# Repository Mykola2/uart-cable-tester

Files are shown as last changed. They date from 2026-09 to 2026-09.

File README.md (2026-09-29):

# RPi ↔ CUAV X7 telemetry cable tester

A production tester for the harness that runs from a Raspberry Pi 40-pin header to 3× JST-GH 6-pin (CUAV X7 TELEM1–3). Plug a cable in and get a PASS/FAIL verdict in under a second, with a colour per wire:

| Colour | Meaning |
|---|---|
| green | OK |
| red | open |
| orange | miswired (swapped, wrong cavity, wrong pin) |
| magenta | short |

A wiggle test catches intermittent crimps.

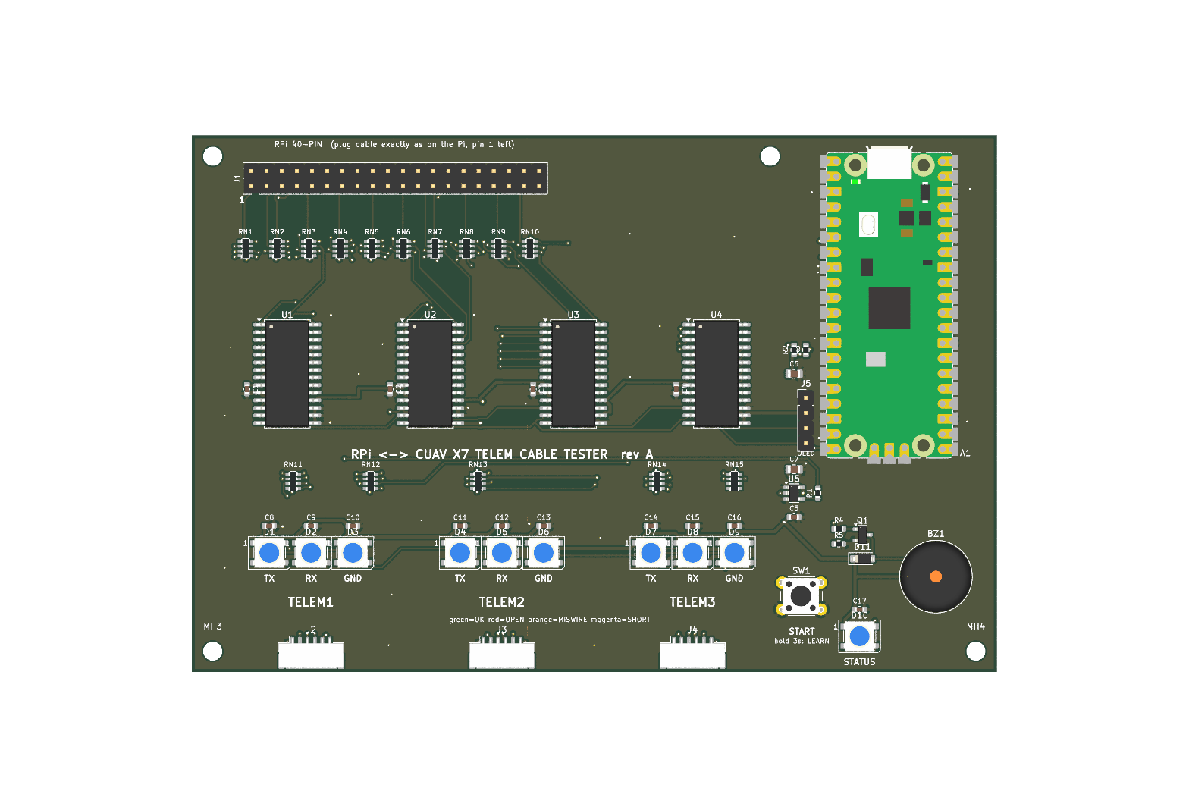
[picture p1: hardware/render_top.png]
board


## How it works
- **Test lines.** Every contact on the 40-pin header and on the three JSTs (58 lines) has its own MCP23017 I/O pin, through a 220 Ω resistor. The header's power and GND pins are isolated test lines too.
- **Scan.** The RP2040 drives one line low at a time and reads all the others (a "walking one" scan). That builds the full connection map, which it compares to `wiring.json`.
- **Changing the pinout** needs no new hardware. Either edit `wiring.json` on the board's USB drive, or plug in a known-good cable and hold the button for 3 s (learn mode).
- **Ground wires** may land on any Pi GND pin, because the Pi's grounds are common.

## Layout
| Path | Contents |
|---|---|
| `firmware/` | CircuitPython firmware and PC simulation tests. See [firmware/README.md](firmware/README.md). |
| `hardware/` | KiCad 9 project, generator and check scripts, BOM. See [hardware/README.md](hardware/README.md). |
| `hardware/fab/` | JLCPCB order files: Gerber zip, `BOM_JLC.csv`, `CPL_JLC.csv`. |

## Quick commands
```bash
python firmware/pc_tests/test_tester.py      # firmware logic tests
python hardware/check_design.py              # netlist vs firmware pin map
python hardware/make_jlc.py                  # regenerate JLCPCB files from the board
```

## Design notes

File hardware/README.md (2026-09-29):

# Cable tester PCB (KiCad 9)

`design.py` is the single source of truth: parts, footprints, pin-to-net map and positions.
Everything else is generated from it.

| File | What it is |
|---|---|
| `cable_tester.kicad_sch` | Schematic. Every pin is connected by a net label; opens normally in KiCad. |
| `cable_tester.kicad_pcb` | Board, 135×90 mm, 2 layers. Routed with Freerouting, GND pours on both layers. DRC is clean apart from silkscreen warnings. |
| `BOM.csv` | Grouped BOM with MPNs. `fab/BOM_JLC.csv` has the verified LCSC numbers. |
| `fab/` | JLCPCB files (Gerber zip, BOM, CPL), regenerated by `make_jlc.py`. |
| `move_decoupling.py` | One-off fix already applied to the routed board: moved C1–C4 next to the MCP23017 VDD pins. |
| `cable_tester_schematic.pdf`, `render_top.png`, `render_bottom.png` | Previews of the schematic and the board. |

## Regenerate

```bash
python gen_schematic.py
"C:/Program Files/KiCad/9.0/bin/kicad-cli.exe" sch erc cable_tester.kicad_sch
"C:/Program Files/KiCad/9.0/bin/kicad-cli.exe" sch export netlist --format kicadsexpr -o cable_tester.net cable_tester.kicad_sch
python check_design.py
"C:/Program Files/KiCad/9.0/bin/python.exe" gen_pcb.py
```

`check_design.py` checks the exported netlist against `firmware/hwmap.py`:
- each of the 58 test lines runs connector pin → 220 Ω → the MCP23017 pin the firmware expects
- the address straps are correct
- no DUT pin touches a power net

**The board is routed, so don't run `gen_pcb.py` again**, because it overwrites the board.
After that, make changes in the schematic (or `design.py` followed by `gen_schematic.py`), then use *Tools → Update PCB from Schematic* (F8).

## Circuit summary
- **A1**: Raspberry Pi Pico or a WeAct RP2040 (USB-C, same pinout).
  - USB supplies VBUS (+5 V), which powers the LEDs and buzzer.
  - The module's 3V3 output powers the MCP23017s.
  - Pins used: GP4 SDA, GP5 SCL, GP14 buzzer, GP15 button, GP16 LED data.
- **U1–U4**: MCP23017 at I²C addresses 0x20–0x23. Every DUT contact goes to its own expander pin through one resistor in RN1–RN15 (4×220 Ω arrays).
  - U1: H1–16. U2: H17–32. U3: GPA = H33–40, GPB0–5 = TELEM1.
  - U4: GPA0–5 = TELEM2, GPB0–5 = TELEM3.
  - Spare lines: U3 GPB6–7, U4 GPA6–7, U4 GPB6–7.
- **J1**: the 40-pin header. **None of its pins touch GND, 3V3 or 5V.** Each one is an isolated test line, which is why any future pinout can be tested with a config change only.
- **D1–D10**: WS2812B, driven through U5 (74AHCT1G125) to shift the data line from 3.3 V to 5 V.
  - D1–D9 are the wire LEDs: TX / RX / GND for each TELEM connector.
  - D10 is the PASS/FAIL status LED.
- **BZ1**: 5 V active buzzer, switched by Q1 with flyback diode D11.
- **SW1**: START / LEARN button.
- **J5**: optional SSD1306 OLED header. The firmware doesn't drive it yet.

## Before ordering
1. **Route it.** Freerouting works well:
   - export with *File → Export → Specctra DSN*, route in Freerouting, then import the `.ses` file
   - press **B** to fill the GND pours
   - run DRC
2. **Check JST orientation in the 3D viewer (Alt+3).** The TELEM connectors must open toward the bottom board edge.
3. **Check the header orientation.** It copies a Pi seen from above: pin 1 is bottom-left on the silkscreen, and the even-pin row is along the board edge. The cable must plug in exactly as it does on the Pi.
4. **Check the module footprint.** If you use a Pico clone, confirm it matches `RaspberryPi_Pico_SMD_HandSolder`.
5. **JST-GH receptacles are consumables.** They are rated for only ~50 mating cycles. Order spares and replace them with hot air when mating gets loose.

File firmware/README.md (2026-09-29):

# Cable tester firmware (CircuitPython)

## Install
1. Hold BOOTSEL, plug in USB, and drop the CircuitPython UF2 for **Raspberry Pi Pico** onto the RPI-RP2 drive (circuitpython.org). The Pico build also runs on the WeAct RP2040.
2. Copy `code.py`, `hwmap.py`, `mcp_bus.py`, `tester.py` and `wiring.json` to the `CIRCUITPY` drive. No libraries are needed.
3. Open the serial console (Mu, Thonny or PuTTY at any baud rate). You should see `# cable tester ready` followed by a CSV header.

## Use
- **Plug the cable in.**
  - A good cable passes about 0.3 s after it's fully connected: all wire LEDs turn green, the status LED turns green, and it gives one short beep.
  - A fault that stays for 3 s gives FAIL: status LED red and a long beep. The wire LEDs show the fault type:

| Wire LED | Meaning |
|---|---|
| green | OK |
| red | OPEN |
| orange | MISWIRE (swapped, wrong cavity or wrong header pin) |
| magenta | SHORT |

- **Wiggle test.** After a PASS, flex the cable near each crimp. A fault that appears and clears within 2 s is logged as INTERMITTENT: the status LED blinks red and the affected wire LED blinks.
- **Unplug.** The tester returns to idle (status LED dim blue) after 1 s with nothing connected.
- **Short press:** during a test, forces the verdict now; after a verdict, starts a retest.
- **Hold 3 s with a known-good cable plugged in:** LEARN.
  - The tester stores the cable's wiring in NVM, prints it as JSON (ready to paste into `wiring.json`), and beeps once per net (9 beeps expected).
- **Hold 3 s with nothing plugged in:** clears the learned map and goes back to `wiring.json`.
- Editing `wiring.json` also overrides an old learned map.

The serial log is CSV (`time_s,count,result,faults`), e.g. `412.3,57,FAIL,T2_RX OPEN [T2.3] | [H7]`.

## Pinout changes
Edit `wiring.json` on the CIRCUITPY drive, or use LEARN.
- Pins are named `H1`–`H40` (RPi header numbering) and `T1.1`–`T3.6` (TELEM connector.pin).
- `leds` says which JST pin each wire LED reports.
- **The default map is a placeholder.** It is TELEM1 = UART0 (pins 8/10), TELEM2 = UART3 (7/29) and TELEM3 = UART5 (32/33). Confirm it against your cable drawing.
- **Ground wires can go to any Pi GND pin.** A net entry such as `"T1_GND": ["T1.6", "PI_GND"]` passes if the wire reaches any pin listed under `any_of.PI_GND` (6, 9, 14, 20, 25, 30, 34 or 39).
  - Several GND wires sharing one GND pin is fine. So is a bridge between two GND pins, because they are common on the Pi.
  - A GND wire on a non-GND pin, or a GND pin bridged to a signal pin, still fails.
  - `PI_5V` (2, 4) and `PI_3V3` (1, 17) groups are defined the same way, ready for future cables.
- Signal wires (TX/RX) are still checked against their exact header pin.
- LEARN stores the ground wires of a known-good cable as `PI_GND` too, not as the specific pin that cable happened to use.

## PC tests
```bash
python pc_tests/test_tester.py
```
These simulate the four MCP23017s at register level together with a set of cables (good, open, TX/RX swap, short, wrong cavity, stray bridge, stuck line, learn) and the PASS/FAIL/INTERMITTENT state machine.

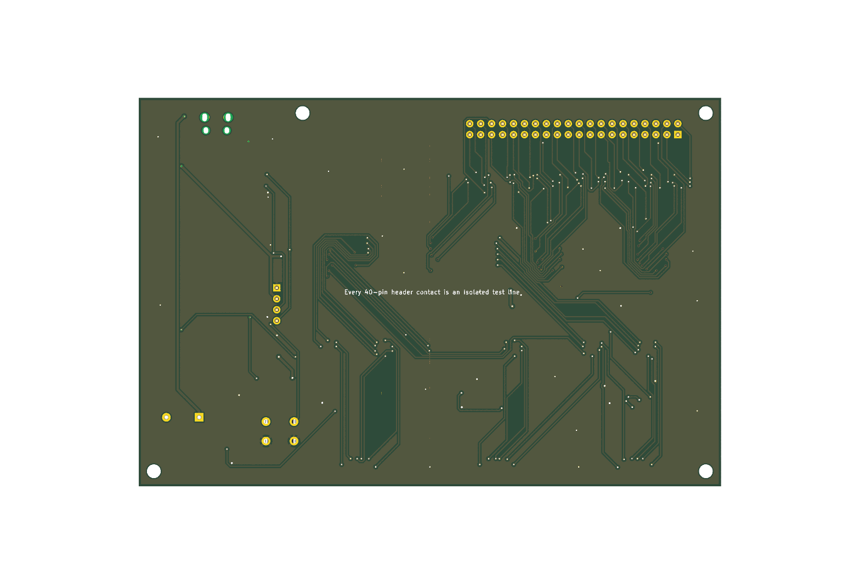
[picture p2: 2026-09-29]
hardware/render_bottom.png

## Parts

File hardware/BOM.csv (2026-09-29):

Qty | References | Value | Footprint | MPN | LCSC (fill in) | Notes
1 | A1 | Pico / WeAct RP2040 (USB-C) | Module:RaspberryPi_Pico_SMD_HandSolder | Raspberry Pi Pico (SC0915) or WeAct Studio RP2040 |  | USB-C variant recommended; castellated, solder directly or on 2x 1x20 sockets
1 | BZ1 | 5V active buzzer | Buzzer_Beeper:Buzzer_12x9.5RM7.6 | TMB12A05 (12mm 5V active, 7.6mm pitch)
15 | C1 C2 C3 C4 C5 C8 C9 C10 C11 C12 C13 C14 C15 C16 C17 | 100n | Capacitor_SMD:C_0603_1608Metric | 0603 100nF X7R 16V
2 | C6 C7 | 10u | Capacitor_SMD:C_0805_2012Metric | 0805 10uF X5R 16V
10 | D1 D2 D3 D4 D5 D6 D7 D8 D9 D10 | WS2812B | LED_SMD:LED_WS2812B_PLCC4_5.0x5.0mm_P3.2mm | WS2812B-5050
1 | D11 | 1N4148W | Diode_SMD:D_SOD-123 | 1N4148W
1 | J1 | RPi 40-pin (DUT) | Connector_PinHeader_2.54mm:PinHeader_2x20_P2.54mm_Vertical | 2x20 2.54mm male pin header |  | ALL pins are isolated test lines - never tie to power/GND
1 | J2 | TELEM1 (DUT) | Connector_JST:JST_GH_SM06B-GHS-TB_1x06-1MP_P1.25mm_Horizontal | JST SM06B-GHS-TB(LF)(SN) |  | ~50 mating cycles: consumable, keep spares
1 | J3 | TELEM2 (DUT) | Connector_JST:JST_GH_SM06B-GHS-TB_1x06-1MP_P1.25mm_Horizontal | JST SM06B-GHS-TB(LF)(SN) |  | ~50 mating cycles: consumable, keep spares
1 | J4 | TELEM3 (DUT) | Connector_JST:JST_GH_SM06B-GHS-TB_1x06-1MP_P1.25mm_Horizontal | JST SM06B-GHS-TB(LF)(SN) |  | ~50 mating cycles: consumable, keep spares
1 | J5 | OLED (opt.) | Connector_PinHeader_2.54mm:PinHeader_1x04_P2.54mm_Vertical | 1x4 2.54mm header (DNP) |  | SSD1306 128x64 I2C, GND-VCC-SCL-SDA
1 | Q1 | MMBT3904 | Package_TO_SOT_SMD:SOT-23 | MMBT3904
1 | R1 | 330 | Resistor_SMD:R_0603_1608Metric | 0603 330R
2 | R2 R3 | 4k7 | Resistor_SMD:R_0603_1608Metric | 0603 4.7k
1 | R4 | 1k | Resistor_SMD:R_0603_1608Metric | 0603 1k
1 | R5 | 10k | Resistor_SMD:R_0603_1608Metric | 0603 10k
15 | RN1 RN2 RN3 RN4 RN5 RN6 RN7 RN8 RN9 RN10 RN11 RN12 RN13 RN14 RN15 | 4x220 | Resistor_SMD:R_Array_Convex_4x0603 | YC164-JR-07220RL (4x220R 0603 convex)
1 | SW1 | START / LEARN | Button_Switch_THT:SW_PUSH_6mm_H5mm | 6x6mm THT tactile switch |  | short press: retest / force verdict; hold 3s: learn
4 | U1 U2 U3 U4 | MCP23017-E/SO | Package_SO:SOIC-28W_7.5x17.9mm_P1.27mm | MCP23017-E/SO |  | I2C addr 0x20; I2C addr 0x21; I2C addr 0x22; I2C addr 0x23
1 | U5 | 74AHCT1G125 | Package_TO_SOT_SMD:SOT-23-5 | SN74AHCT1G125DBVR

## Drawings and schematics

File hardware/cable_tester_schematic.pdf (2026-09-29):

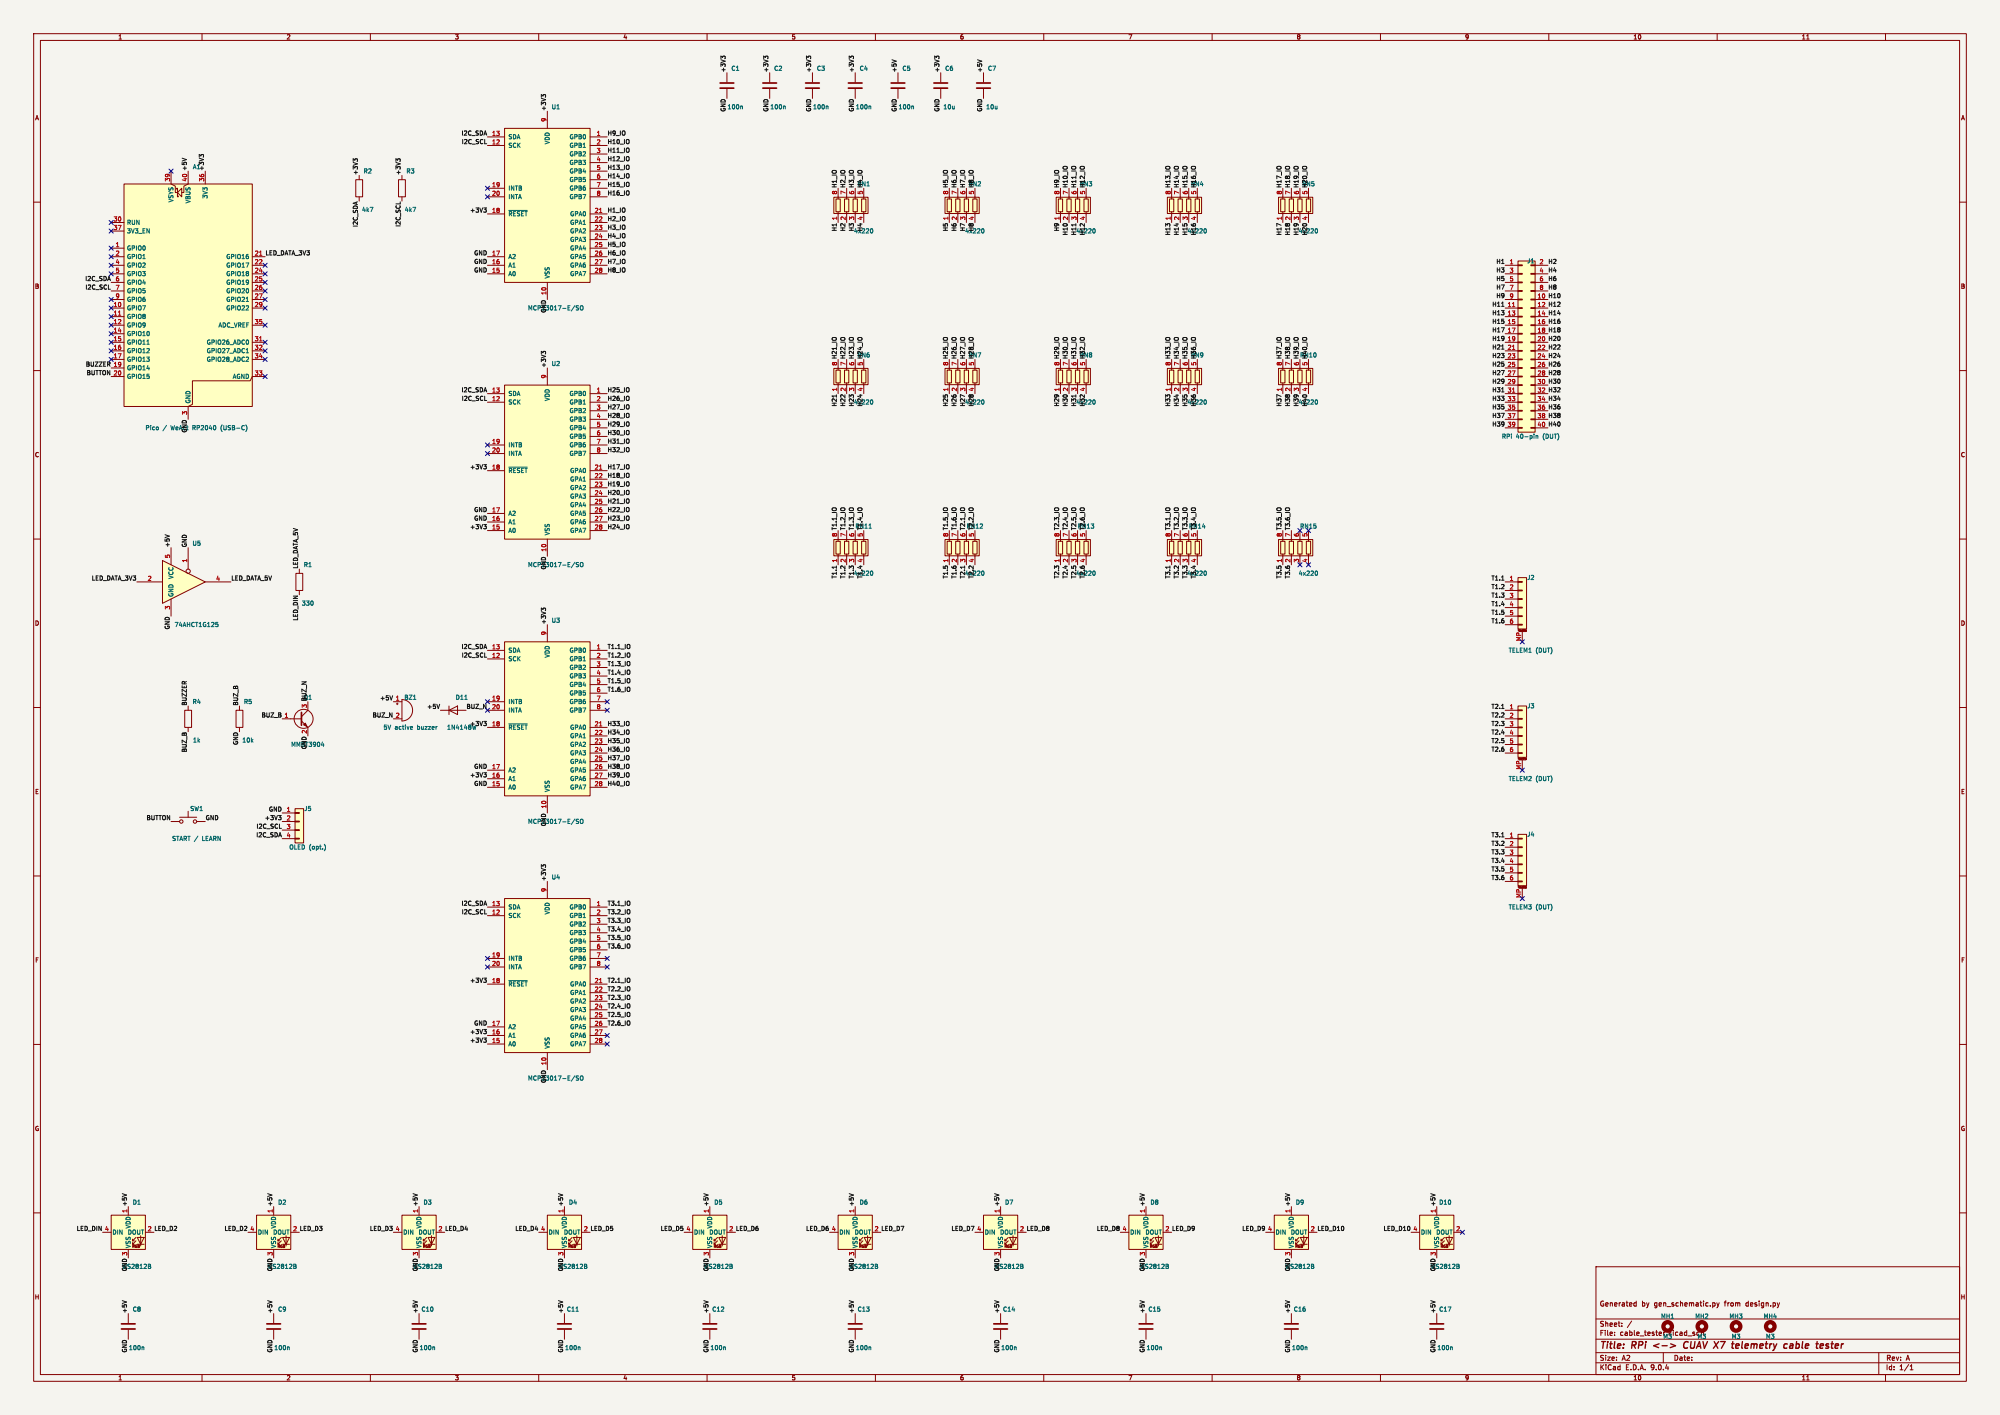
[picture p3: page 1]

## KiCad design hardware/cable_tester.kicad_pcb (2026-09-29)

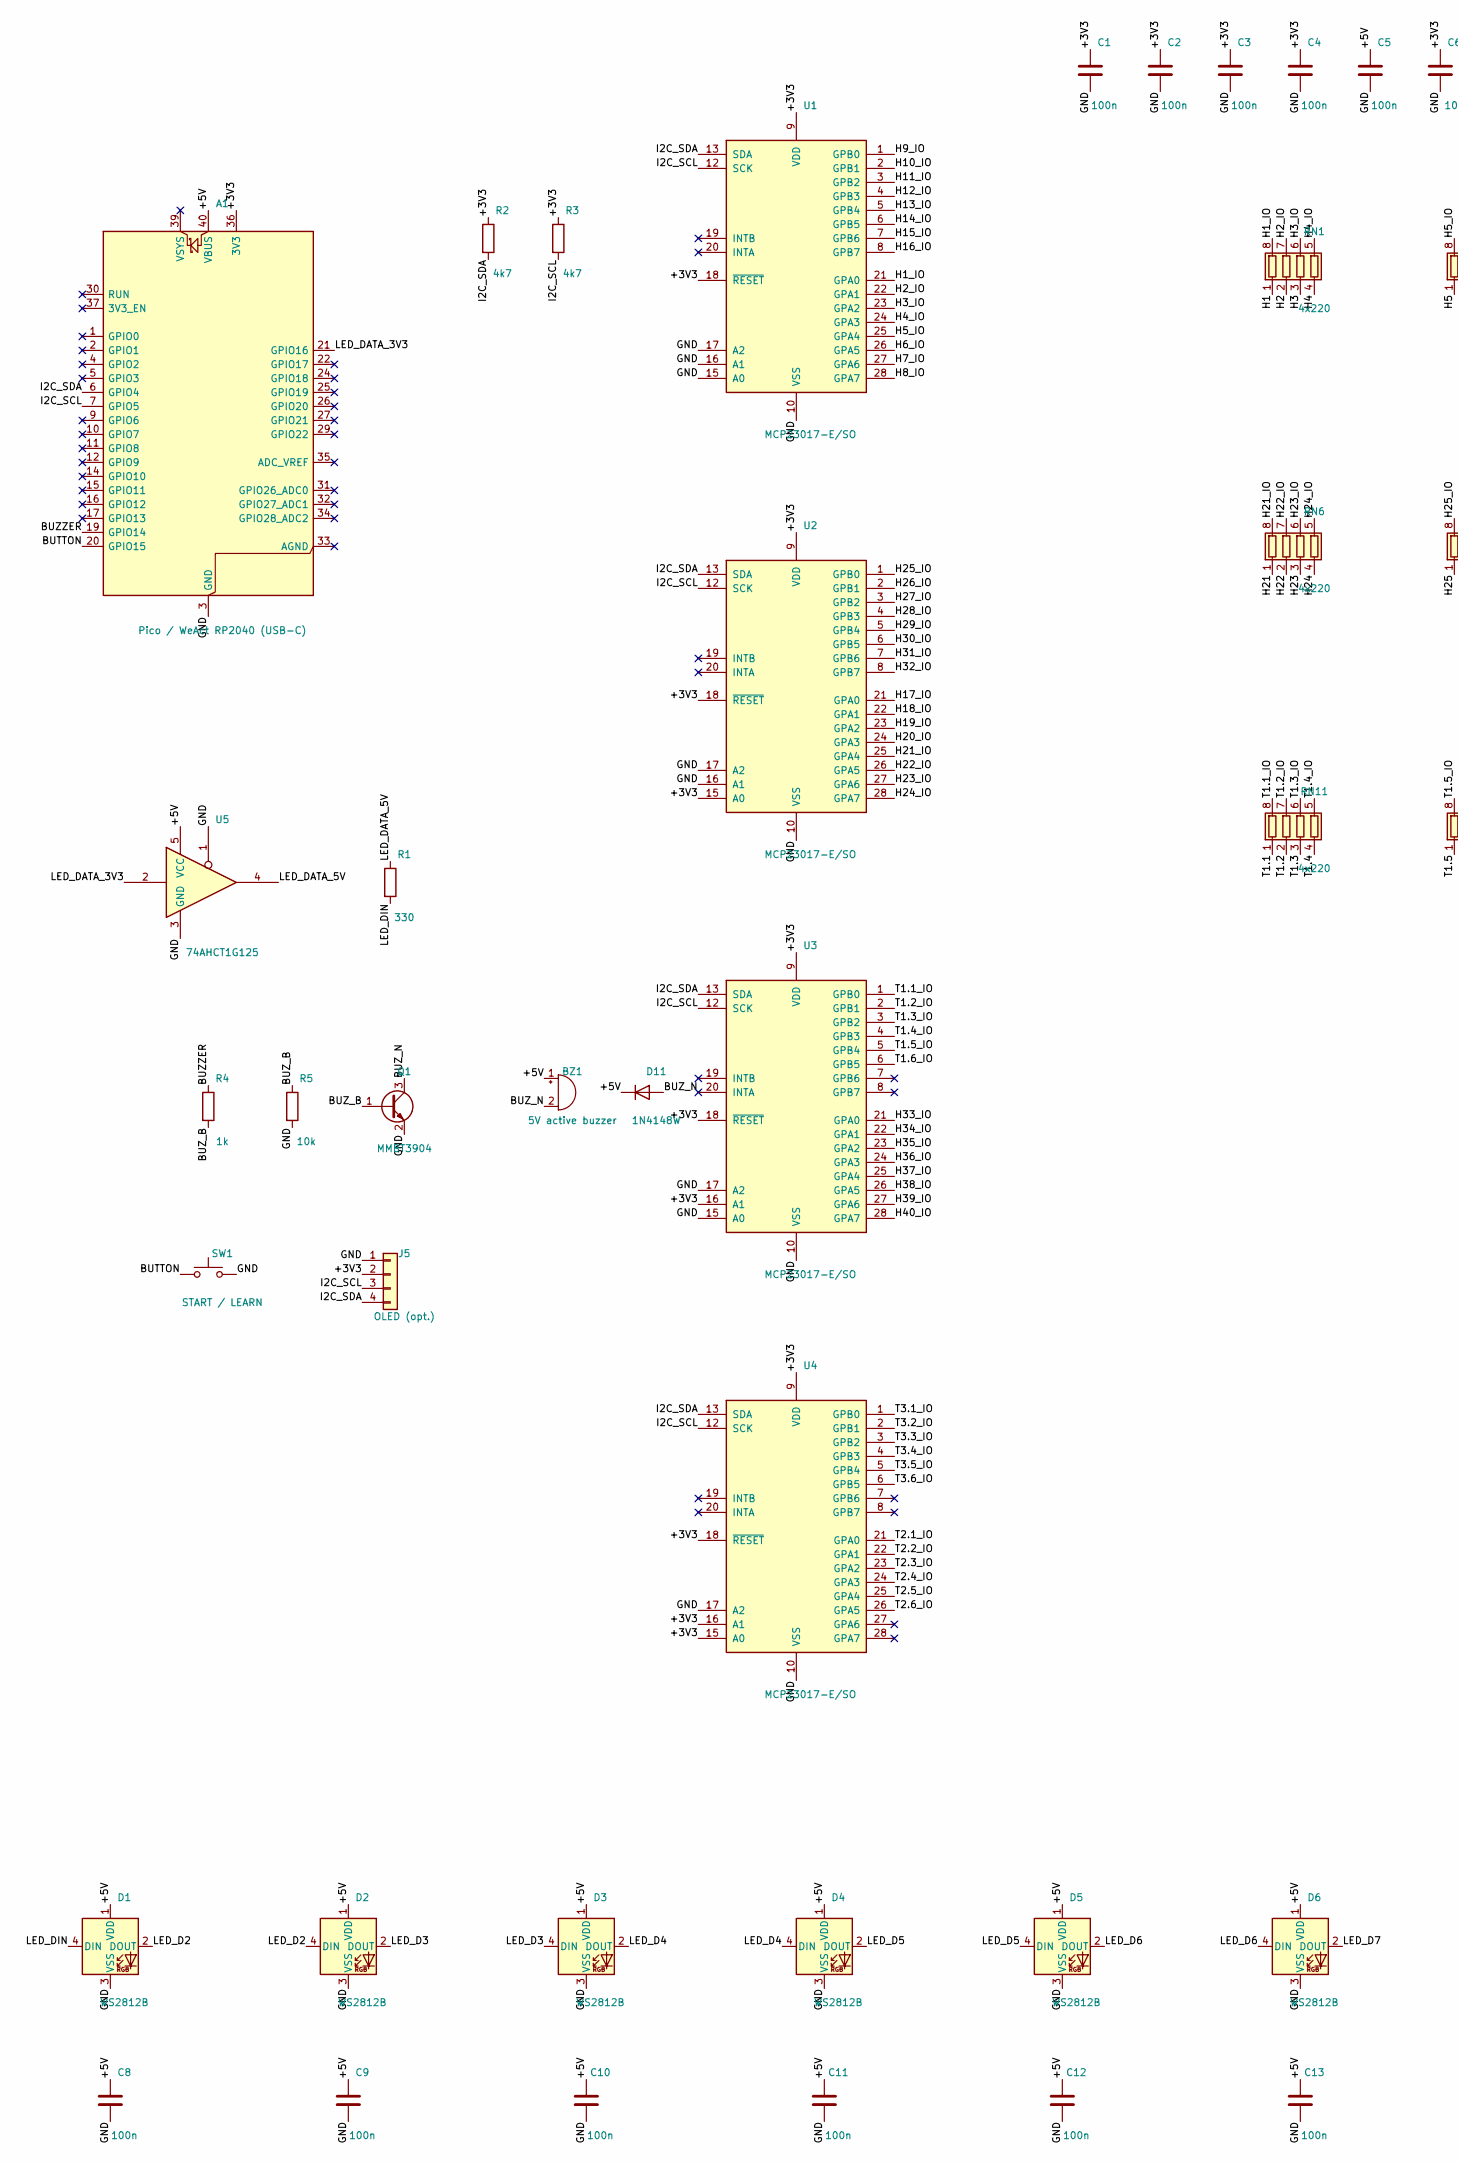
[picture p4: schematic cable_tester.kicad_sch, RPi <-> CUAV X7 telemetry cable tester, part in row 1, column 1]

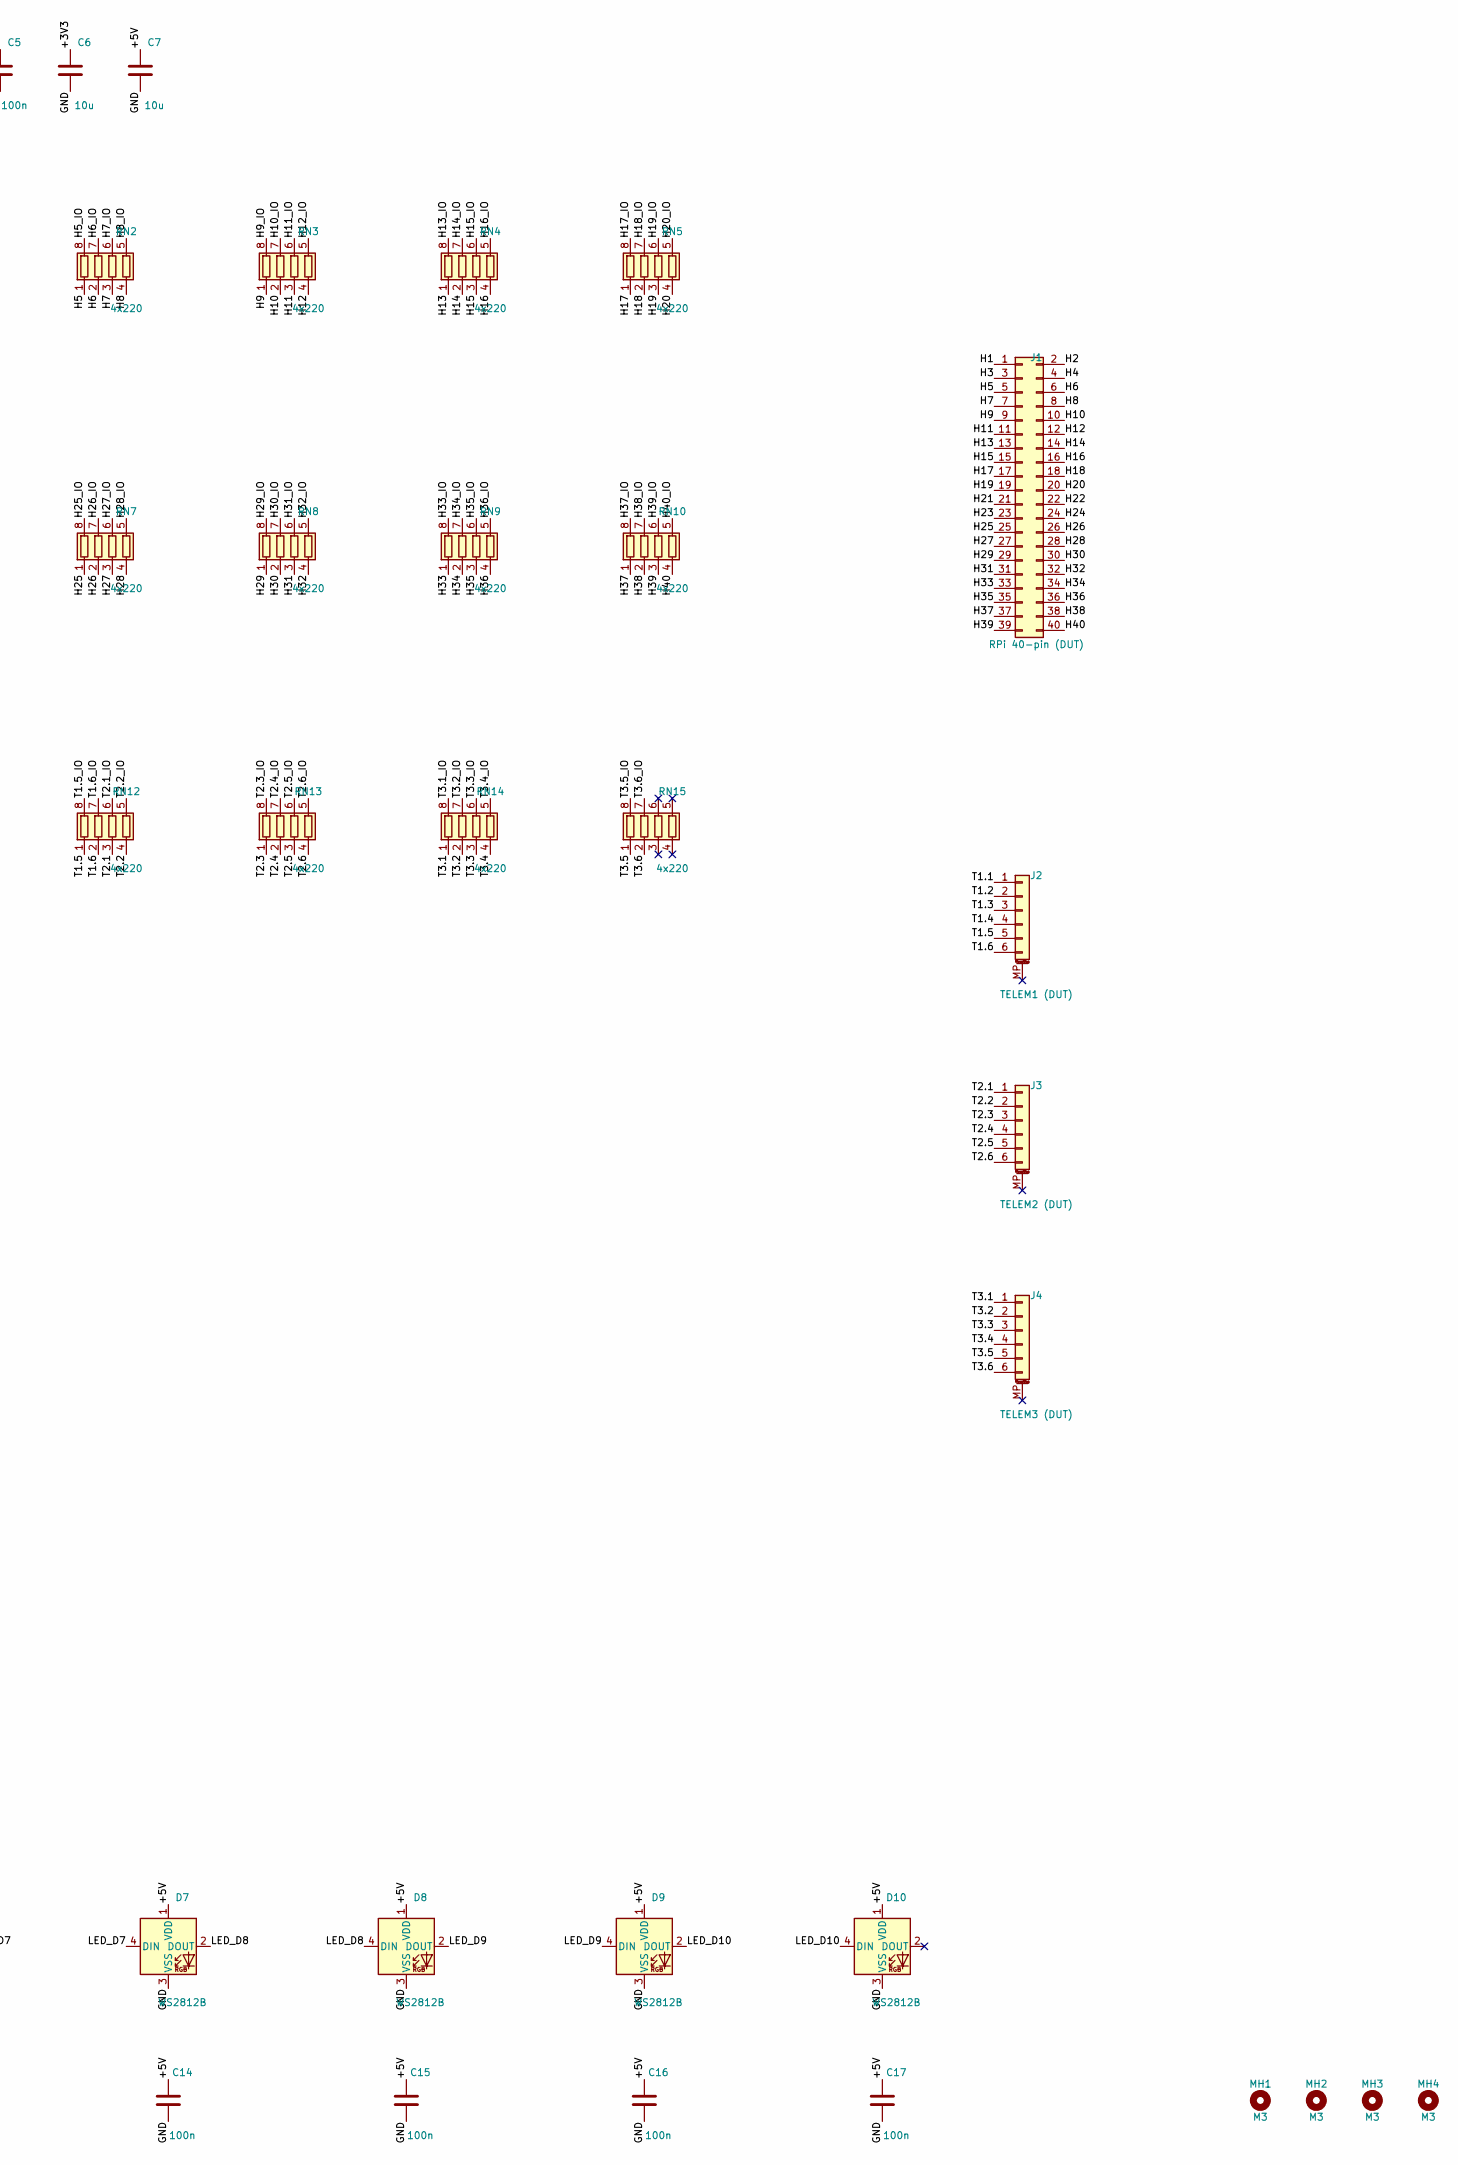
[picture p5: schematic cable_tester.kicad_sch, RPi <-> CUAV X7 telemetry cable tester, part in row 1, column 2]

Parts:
A1: Pico / WeAct RP2040 (USB-C); RaspberryPi_Pico_SMD_HandSolder; MPN Raspberry Pi Pico (SC0915) or WeAct Stu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
BZ1: 5V active buzzer; Buzzer_12x9.5RM7.6; MPN TMB12A05 (12mm 5V active, 7.6mm pitch)
C1, C2, C3, C4, C5, C8, C9, C10, C11, C12, C13, C14, C15, C16, C17: 100n; C_0603_1608Metric; MPN 0603 100nF X7R 16V
C6, C7: 10u; C_0805_2012Metric; MPN 0805 10uF X5R 16V
D1, D2, D3, D4, D5, D6, D7, D8, D9, D10: WS2812B; LED_WS2812B_PLCC4_5.0x5.0mm_P3.2mm; MPN WS2812B-5050
D11: 1N4148W; D_SOD-123; MPN 1N4148W
J1: RPi 40-pin (DUT); PinHeader_2x20_P2.54mm_Vertical; MPN 2x20 2.54mm male pin header
J2: TELEM1 (DUT); JST_GH_SM06B-GHS-TB_1x06-1MP_P1.25mm_Horizontal; MPN JST SM06B-GHS-TB(LF)(SN)
J3: TELEM2 (DUT); JST_GH_SM06B-GHS-TB_1x06-1MP_P1.25mm_Horizontal; MPN JST SM06B-GHS-TB(LF)(SN)
J4: TELEM3 (DUT); JST_GH_SM06B-GHS-TB_1x06-1MP_P1.25mm_Horizontal; MPN JST SM06B-GHS-TB(LF)(SN)
J5: OLED (opt.); PinHeader_1x04_P2.54mm_Vertical; MPN 1x4 2.54mm header (DNP)
MH1, MH2, MH3, MH4: M3; MountingHole_3.2mm_M3; MPN (none)
Q1: MMBT3904; SOT-23; MPN MMBT3904
R1: 330; R_0603_1608Metric; MPN 0603 330R
R2, R3: 4k7; R_0603_1608Metric; MPN 0603 4.7k
R4: 1k; R_0603_1608Metric; MPN 0603 1k
R5: 10k; R_0603_1608Metric; MPN 0603 10k
RN1, RN2, RN3, RN4, RN5, RN6, RN7, RN8, RN9, RN10, RN11, RN12, RN13, RN14, RN15: 4x220; R_Array_Convex_4x0603; MPN YC164-JR-07220RL (4x220R 0603 convex)
SW1: START / LEARN; SW_PUSH_6mm_H5mm; MPN 6x6mm THT tactile switch
U1, U2, U3, U4: MCP23017-E/SO; SOIC-28W_7.5x17.9mm_P1.27mm; MPN MCP23017-E/SO
U5: 74AHCT1G125; SOT-23-5; MPN SN74AHCT1G125DBVR

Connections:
/+3V3: A1.36 (3V3), C1.1, C2.1, C3.1, C4.1, C6.1, J5.2, R2.1, R3.1, U1.9 (VDD), U1.18 (~RESET), U2.9 (VDD), U2.15 (A0), U2.18 (~RESET), U3.9 (VDD), U3.16 (A1), U3.18 (~RESET), U4.9 (VDD), U4.15 (A0), U4.16 (A1), U4.18 (~RESET)
/+5V: A1.40 (VBUS), BZ1.1 (+), C5.1, C7.1, C8.1, C9.1, C10.1, C11.1, C12.1, C13.1, C14.1, C15.1, C16.1, C17.1, D1.1 (VDD), D2.1 (VDD), D3.1 (VDD), D4.1 (VDD), D5.1 (VDD), D6.1 (VDD), D7.1 (VDD), D8.1 (VDD), D9.1 (VDD), D10.1 (VDD), D11.1 (K), U5.5 (VCC)
/BUTTON: A1.20 (GPIO15), SW1.1
/BUZZER: A1.19 (GPIO14), R4.1
/BUZ_B: Q1.1 (B), R4.2, R5.1
/BUZ_N: BZ1.2 (-), D11.2 (A), Q1.3 (C)
/GND: A1.3 (GND), A1.8 (GND), A1.13 (GND), A1.18 (GND), A1.23 (GND), A1.28 (GND), A1.38 (GND), C1.2, C2.2, C3.2, C4.2, C5.2, C6.2, C7.2, C8.2, C9.2, C10.2, C11.2, C12.2, C13.2, C14.2, C15.2, C16.2, C17.2, D1.3 (VSS), D2.3 (VSS), D3.3 (VSS), D4.3 (VSS), D5.3 (VSS), D6.3 (VSS), D7.3 (VSS), D8.3 (VSS), D9.3 (VSS), D10.3 (VSS), J5.1, Q1.2 (E), R5.2, SW1.2, U1.10 (VSS), U1.15 (A0), U1.16 (A1), U1.17 (A2), U2.10 (VSS), U2.16 (A1), U2.17 (A2), U3.10 (VSS), U3.15 (A0), U3.17 (A2), U4.10 (VSS), U4.17 (A2), U5.1, U5.3 (GND)
/H1: J1.1, RN1.1 (R1.1)
/H1_IO: RN1.8 (R1.2), U1.21 (GPA0)
/H2: J1.2, RN1.2 (R2.1)
/H2_IO: RN1.7 (R2.2), U1.22 (GPA1)
/H3: J1.3, RN1.3 (R3.1)
/H3_IO: RN1.6 (R3.2), U1.23 (GPA2)
/H4: J1.4, RN1.4 (R4.1)
/H4_IO: RN1.5 (R4.2), U1.24 (GPA3)
/H5: J1.5, RN2.1 (R1.1)
/H5_IO: RN2.8 (R1.2), U1.25 (GPA4)
/H6: J1.6, RN2.2 (R2.1)
/H6_IO: RN2.7 (R2.2), U1.26 (GPA5)
/H7: J1.7, RN2.3 (R3.1)
/H7_IO: RN2.6 (R3.2), U1.27 (GPA6)
/H8: J1.8, RN2.4 (R4.1)
/H8_IO: RN2.5 (R4.2), U1.28 (GPA7)
/H9: J1.9, RN3.1 (R1.1)
/H9_IO: RN3.8 (R1.2), U1.1 (GPB0)
/H10: J1.10, RN3.2 (R2.1)
/H10_IO: RN3.7 (R2.2), U1.2 (GPB1)
/H11: J1.11, RN3.3 (R3.1)
/H11_IO: RN3.6 (R3.2), U1.3 (GPB2)
/H12: J1.12, RN3.4 (R4.1)
/H12_IO: RN3.5 (R4.2), U1.4 (GPB3)
/H13: J1.13, RN4.1 (R1.1)
/H13_IO: RN4.8 (R1.2), U1.5 (GPB4)
/H14: J1.14, RN4.2 (R2.1)
/H14_IO: RN4.7 (R2.2), U1.6 (GPB5)
/H15: J1.15, RN4.3 (R3.1)
/H15_IO: RN4.6 (R3.2), U1.7 (GPB6)
/H16: J1.16, RN4.4 (R4.1)
/H16_IO: RN4.5 (R4.2), U1.8 (GPB7)
/H17: J1.17, RN5.1 (R1.1)
/H17_IO: RN5.8 (R1.2), U2.21 (GPA0)
/H18: J1.18, RN5.2 (R2.1)
/H18_IO: RN5.7 (R2.2), U2.22 (GPA1)
/H19: J1.19, RN5.3 (R3.1)
/H19_IO: RN5.6 (R3.2), U2.23 (GPA2)
/H20: J1.20, RN5.4 (R4.1)
/H20_IO: RN5.5 (R4.2), U2.24 (GPA3)
/H21: J1.21, RN6.1 (R1.1)
/H21_IO: RN6.8 (R1.2), U2.25 (GPA4)
/H22: J1.22, RN6.2 (R2.1)
/H22_IO: RN6.7 (R2.2), U2.26 (GPA5)
/H23: J1.23, RN6.3 (R3.1)
/H23_IO: RN6.6 (R3.2), U2.27 (GPA6)
/H24: J1.24, RN6.4 (R4.1)
/H24_IO: RN6.5 (R4.2), U2.28 (GPA7)
/H25: J1.25, RN7.1 (R1.1)
/H25_IO: RN7.8 (R1.2), U2.1 (GPB0)
/H26: J1.26, RN7.2 (R2.1)
/H26_IO: RN7.7 (R2.2), U2.2 (GPB1)
/H27: J1.27, RN7.3 (R3.1)
/H27_IO: RN7.6 (R3.2), U2.3 (GPB2)
/H28: J1.28, RN7.4 (R4.1)
/H28_IO: RN7.5 (R4.2), U2.4 (GPB3)
/H29: J1.29, RN8.1 (R1.1)
/H29_IO: RN8.8 (R1.2), U2.5 (GPB4)
/H30: J1.30, RN8.2 (R2.1)
/H30_IO: RN8.7 (R2.2), U2.6 (GPB5)
/H31: J1.31, RN8.3 (R3.1)
/H31_IO: RN8.6 (R3.2), U2.7 (GPB6)
/H32: J1.32, RN8.4 (R4.1)
/H32_IO: RN8.5 (R4.2), U2.8 (GPB7)
/H33: J1.33, RN9.1 (R1.1)
/H33_IO: RN9.8 (R1.2), U3.21 (GPA0)
/H34: J1.34, RN9.2 (R2.1)
/H34_IO: RN9.7 (R2.2), U3.22 (GPA1)
/H35: J1.35, RN9.3 (R3.1)
/H35_IO: RN9.6 (R3.2), U3.23 (GPA2)
/H36: J1.36, RN9.4 (R4.1)
/H36_IO: RN9.5 (R4.2), U3.24 (GPA3)
/H37: J1.37, RN10.1 (R1.1)
/H37_IO: RN10.8 (R1.2), U3.25 (GPA4)
/H38: J1.38, RN10.2 (R2.1)
/H38_IO: RN10.7 (R2.2), U3.26 (GPA5)
/H39: J1.39, RN10.3 (R3.1)
/H39_IO: RN10.6 (R3.2), U3.27 (GPA6)
/H40: J1.40, RN10.4 (R4.1)
/H40_IO: RN10.5 (R4.2), U3.28 (GPA7)
/I2C_SCL: A1.7 (GPIO5), J5.3, R3.2, U1.12 (SCK), U2.12 (SCK), U3.12 (SCK), U4.12 (SCK)
/I2C_SDA: A1.6 (GPIO4), J5.4, R2.2, U1.13 (SDA), U2.13 (SDA), U3.13 (SDA), U4.13 (SDA)
/LED_D2: D1.2 (DOUT), D2.4 (DIN)
/LED_D3: D2.2 (DOUT), D3.4 (DIN)
/LED_D4: D3.2 (DOUT), D4.4 (DIN)
/LED_D5: D4.2 (DOUT), D5.4 (DIN)
/LED_D6: D5.2 (DOUT), D6.4 (DIN)
/LED_D7: D6.2 (DOUT), D7.4 (DIN)
/LED_D8: D7.2 (DOUT), D8.4 (DIN)
/LED_D9: D8.2 (DOUT), D9.4 (DIN)
/LED_D10: D9.2 (DOUT), D10.4 (DIN)
/LED_DATA_3V3: A1.21 (GPIO16), U5.2
/LED_DATA_5V: R1.1, U5.4
/LED_DIN: D1.4 (DIN), R1.2
/T1.1: J2.1, RN11.1 (R1.1)
/T1.1_IO: RN11.8 (R1.2), U3.1 (GPB0)
/T1.2: J2.2, RN11.2 (R2.1)
/T1.2_IO: RN11.7 (R2.2), U3.2 (GPB1)
/T1.3: J2.3, RN11.3 (R3.1)
/T1.3_IO: RN11.6 (R3.2), U3.3 (GPB2)
/T1.4: J2.4, RN11.4 (R4.1)
/T1.4_IO: RN11.5 (R4.2), U3.4 (GPB3)
/T1.5: J2.5, RN12.1 (R1.1)
/T1.5_IO: RN12.8 (R1.2), U3.5 (GPB4)
/T1.6: J2.6, RN12.2 (R2.1)
/T1.6_IO: RN12.7 (R2.2), U3.6 (GPB5)
/T2.1: J3.1, RN12.3 (R3.1)
/T2.1_IO: RN12.6 (R3.2), U4.21 (GPA0)
/T2.2: J3.2, RN12.4 (R4.1)
/T2.2_IO: RN12.5 (R4.2), U4.22 (GPA1)
/T2.3: J3.3, RN13.1 (R1.1)
/T2.3_IO: RN13.8 (R1.2), U4.23 (GPA2)
/T2.4: J3.4, RN13.2 (R2.1)
/T2.4_IO: RN13.7 (R2.2), U4.24 (GPA3)
/T2.5: J3.5, RN13.3 (R3.1)
/T2.5_IO: RN13.6 (R3.2), U4.25 (GPA4)
/T2.6: J3.6, RN13.4 (R4.1)
/T2.6_IO: RN13.5 (R4.2), U4.26 (GPA5)
/T3.1: J4.1, RN14.1 (R1.1)
/T3.1_IO: RN14.8 (R1.2), U4.1 (GPB0)
/T3.2: J4.2, RN14.2 (R2.1)
/T3.2_IO: RN14.7 (R2.2), U4.2 (GPB1)
/T3.3: J4.3, RN14.3 (R3.1)
/T3.3_IO: RN14.6 (R3.2), U4.3 (GPB2)
/T3.4: J4.4, RN14.4 (R4.1)
/T3.4_IO: RN14.5 (R4.2), U4.4 (GPB3)
/T3.5: J4.5, RN15.1 (R1.1)
/T3.5_IO: RN15.8 (R1.2), U4.5 (GPB4)
/T3.6: J4.6, RN15.2 (R2.1)
/T3.6_IO: RN15.7 (R2.2), U4.6 (GPB5)

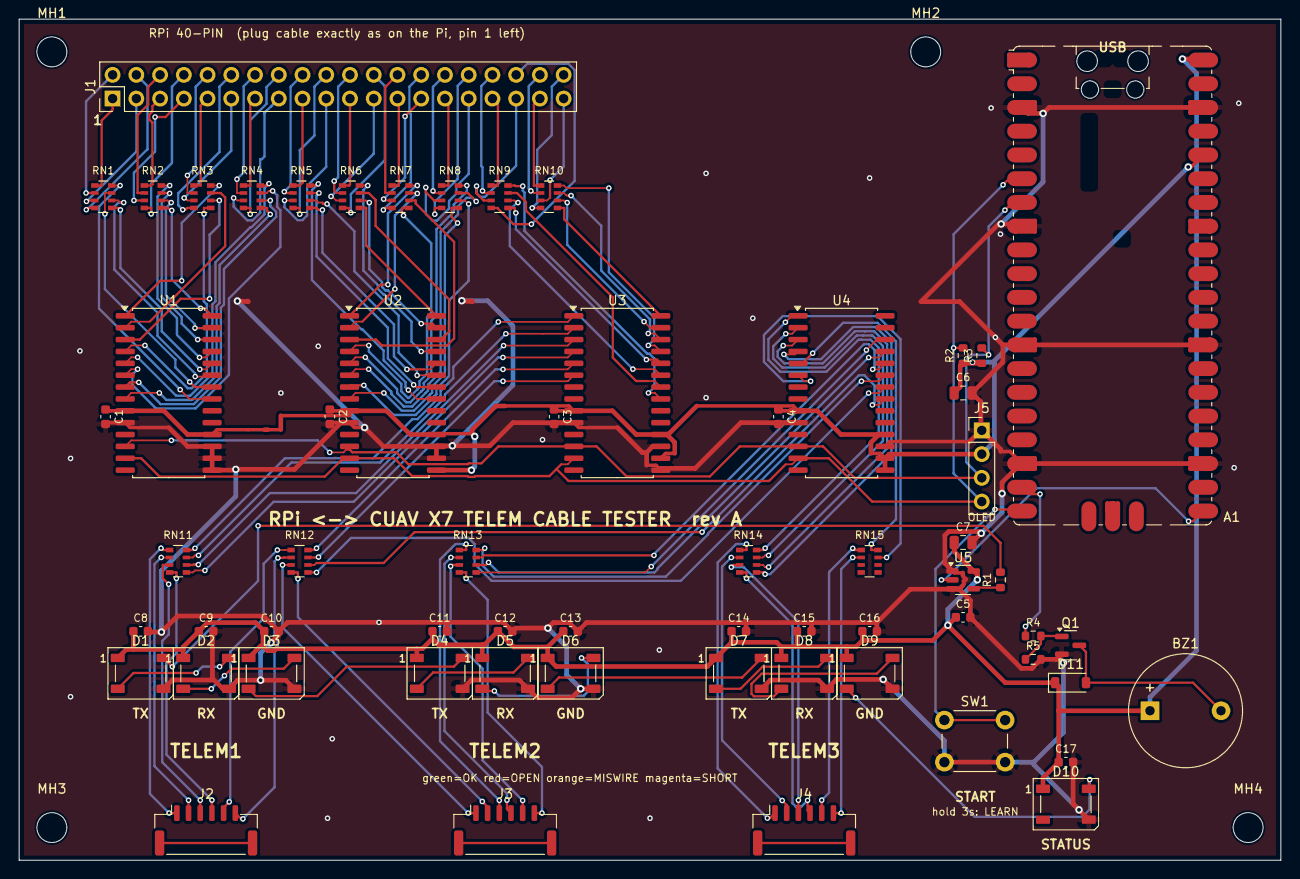
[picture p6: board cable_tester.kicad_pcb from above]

Board: 2 copper layers, 135.0 x 90.0 mm, 66 parts (0 on the bottom side), 137 nets.

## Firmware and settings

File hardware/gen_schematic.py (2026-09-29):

"""Generate cable_tester.kicad_sch (KiCad 9) from design.py.

Symbols are copied from the installed KiCad libraries and every pin is
connected with a net label at its end, so the result is an ordinary,
editable KiCad schematic.

Run:  python gen_schematic.py
"""
import copy
import os
import re
import uuid

import design

KICAD = os.environ.get("KICAD9_DIR", r"C:\Program Files\KiCad\9.0")
SYMDIR = os.path.join(KICAD, "share", "kicad", "symbols")
PROJECT = "cable_tester"
HERE = os.path.dirname(os.path.abspath(__file__))
NS = uuid.UUID("6b1d3f0e-7c1a-4d5e-9a57-cab1e7e57e20")


def uid(*parts):
    return str(uuid.uuid5(NS, "/".join(str(p) for p in parts)))


# ---- tiny s-expression reader/writer ------------------------------------------
class Q(str):
    """A quoted string token."""


TOKEN = re.compile(r'\s*(?:(\()|(\))|"((?:[^"\\]|\\.)*)"|([^\s()"]+))', re.S)


def parse(text):
    stack = [[]]
    pos = 0
    while True:
        m = TOKEN.match(text, pos)
        if not m:
            break
        pos = m.end()
        if m.group(1):
            stack.append([])
        elif m.group(2):
            done = stack.pop()
            stack[-1].append(done)
        elif m.group(3) is not None:
            stack[-1].append(Q(m.group(3).replace('\\"', '"').replace("\\\\", "\\")))
        else:
            stack[-1].append(m.group(4))
    return stack[0][0]


def dump(node, indent=0):
    if not isinstance(node, list):
        if isinstance(node, Q):
            return '"%s"' % node.replace("\\", "\\\\").replace('"', '\\"')
        return str(node)
    simple = all(not isinstance(c, list) for c in node)
    if simple:
        return "(" + " ".join(dump(c) for c in node) + ")"
    pad = "\t" * (indent + 1)
    out = "(" + " ".join(dump(c) for c in node if not isinstance(c, list))
    for c in node:
        if isinstance(c, list):
            out += "\n" + pad + dump(c, indent + 1)
    return out + "\n" + "\t" * indent + ")"


def find(node, key):
    return [c for c in node if isinstance(c, list) and c and c[0] == key]


def first(node, key):
    r = find(node, key)
    return r[0] if r else None


# ---- library access ---------------------------------------------------------------
_libs = {}


def lib(name):
    if name not in _libs:
        with open(os.path.join(SYMDIR, name + ".kicad_sym"), encoding="utf-8") as f:
            _libs[name] = parse(f.read())
    return _libs[name]


def lib_symbol(libname, name):
    """Flattened symbol definition (resolves 'extends')."""
    for s in find(lib(libname), "symbol"):
        if s[1] == name:
            break
    else:
        raise KeyError("%s:%s" % (libname, name))
    ext = first(s, "extends")
    if not ext:
        return copy.deepcopy(s)
    parent = lib_symbol(libname, ext[1])
    out = copy.deepcopy(parent)
    out[1] = Q(name)
    child_props = {p[1]: p for p in find(s, "property")}
    new = []
    for c in out:
        if isinstance(c, list) and c and c[0] == "property" and c[1] in child_props:
            new.append(copy.deepcopy(child_props.pop(c[1])))
        elif isinstance(c, list) and c and c[0] == "symbol":
            c = copy.deepcopy(c)
            c[1] = Q(name + c[1][len(ext[1]):])
            new.append(c)
        else:
            new.append(c)
    # properties only present on the child go after the parent's properties
    idx = max(i for i, c in enumerate(new) if isinstance(c, list) and c and c[0] == "property") + 1
    for p in child_props.values():
        new.insert(idx, copy.deepcopy(p))
        idx += 1
    return new


def symbol_pins(sym):
    """[(unit, number, name, etype, x, y, angle, hidden)] for body style 1."""
    pins = []
    for sub in find(sym, "symbol"):
        m = re.match(r".*_(\d+)_(\d+)$", sub[1])
        unit, style = int(m.group(1)), int(m.group(2))
        if style not in (0, 1):
            continue
        for p in find(sub, "pin"):
            at = first(p, "at")
            hidden = "hide" in p or any(isinstance(c, list) and c[:2] == ["hide", "yes"] for c in p)
            pins.append((unit, first(p, "number")[1], first(p, "name")[1], p[1],
                         float(at[1]), float(at[2]), int(float(at[3])) if len(at) > 3 else 0, hidden))
    return pins


def units_of(sym):
    us = set()
    for sub in find(sym, "symbol"):
        u = int(re.match(r".*_(\d+)_\d+$", sub[1]).group(1))
        if u:
            us.add(u)
    return sorted(us) or [1]


# ---- schematic building ---------------------------------------------------------------
def fmt(v):
    s = ("%.4f" % v).rstrip("0").rstrip(".")
    return "0" if s in ("-0", "") else s


def effects(size=1.27, justify=None, hide=False):
    e = ["effects", ["font", ["size", fmt(size), fmt(size)]]]
    if justify:
        e.append(["justify"] + justify.split())
    if hide:
        e.append(["hide", "yes"])
    return e


def prop(name, value, x, y, hide=False, pid=None):
    return ["property", Q(name), Q(value), ["at", fmt(x), fmt(y), "0"], effects(hide=hide)]


# pin angle (direction from pin end towards the body) -> label angle, justify
LABEL_DIR = {0: ("180", "right bottom"), 180: ("0", "left bottom"),
             90: ("270", "right bottom"), 270: ("90", "left bottom")}


def resolve_pins(part, pins):
    """Map design pin keys (number or name) -> net for each pin number."""
    by_num = {p[1]: p for p in pins}
    netmap = {}
    for key, net in part.pins.items():
        if key in by_num:
            netmap[key] = net
            continue
        hits = [p[1] for p in pins if p[2] == key]
        if not hits:
            raise KeyError("%s: no pin %r in %s:%s" % (part.ref, key, part.lib, part.sym))
        for num in hits:
            netmap[num] = net
    return netmap


def build():
    root = uid("root")
    lib_symbols = ["lib_symbols"]
    body = []
    seen = set()
    nets = {}  # net -> [(ref, pin)]
    for part in design.PARTS:
        lib_id = "%s:%s" % (part.lib, part.sym)
        sym = lib_symbol(part.lib, part.sym)
        if lib_id not in seen:
            seen.add(lib_id)
            emb = copy.deepcopy(sym)
            emb[1] = Q(lib_id)
            lib_symbols.append(emb)
        pins = symbol_pins(sym)
        netmap = resolve_pins(part, pins)
        units = units_of(sym)
        for ui, unit in enumerate(units):
            X, Y = part.sch[0] + 25.4 * ui, part.sch[1]
            su = uid("sym", part.ref, unit)
            inst = ["symbol", ["lib_id", Q(lib_id)], ["at", fmt(X), fmt(Y), "0"], ["unit", str(unit)],
                    ["exclude_from_sim", "no"], ["in_bom", "yes" if part.ref[:2] != "MH" else "no"],
                    ["on_board", "yes"], ["dnp", "no"], ["uuid", Q(su)],
                    prop("Reference", part.ref, X, Y - 3.0),
                    prop("Value", part.value, X, Y + 3.0),
                    prop("Footprint", part.footprint, X, Y, hide=True),
                    prop("Datasheet", "", X, Y, hide=True),
                    prop("MPN", part.mpn, X, Y, hide=True)]
            # Place Reference/Value above/below the pin bbox
            upins = [p for p in pins if p[0] in (0, unit)]
            if upins:
                top = max(p[5] for p in upins)
                bot = min(p[5] for p in upins)
                inst[9][3] = ["at", fmt(X + 2.54), fmt(Y - max(top, 2.54) - 1.27), "0"]
                inst[10][3] = ["at", fmt(X + 2.54), fmt(Y - min(bot, -2.54) + 2.54), "0"]
            for p in upins:
                inst.append(["pin", Q(p[1]), ["uuid", Q(uid("pin", part.ref, p[1]))]])
            inst.append(["instances", ["project", Q(PROJECT),
                         ["path", Q("/" + root), ["reference", Q(part.ref)], ["unit", str(unit)]]]])
            body.append(inst)
            done = {}  # stacked pins (e.g. Pico GND) share one endpoint: label it once
            for (u, num, name, etype, px, py, ang, hidden) in sorted(upins, key=lambda p: (p[7], p[1] not in netmap)):
                ex, ey = X + px, Y - py
                if etype == "no_connect":
                    continue
                net = netmap.get(num)
                key = (round(ex, 3), round(ey, 3))
                if key in done:
                    if net is not None and net != done[key]:
                        raise ValueError("%s: stacked pins on different nets" % part.ref)
                    if net is not None:
                        nets.setdefault(net, []).append((part.ref, num))
                    continue
                done[key] = net
                if net is None:
                    body.append(["no_connect", ["at", fmt(ex), fmt(ey)], ["uuid", Q(uid("nc", part.ref, num))]])
                    continue
                nets.setdefault(net, []).append((part.ref, num))
                la, just = LABEL_DIR[ang % 360]
                body.append(["label", Q(net), ["at", fmt(ex), fmt(ey), la], effects(1.27, just),
                             ["uuid", Q(uid("lbl", part.ref, num))]])
    sch = ["kicad_sch", ["version", "20250114"], ["generator", Q("eeschema")],
           ["generator_version", Q("9.0")], ["uuid", Q(root)], ["paper", Q("A2")],
           ["title_block", ["title", Q("RPi <-> CUAV X7 telemetry cable tester")],
            ["rev", Q("A")], ["comment", "1", Q("Generated by gen_schematic.py from design.py")]],
           lib_symbols] + body + [["sheet_instances", ["path", Q("/"), ["page", Q("1")]]],
                                  ["embedded_fonts", "no"]]
    return sch, nets, root


def write_bom(path):
    groups = {}
    for p in design.PARTS:
        if p.ref.startswith("MH"):
            continue
        groups.setdefault((p.value, p.footprint, p.mpn), []).append(p)

    def refkey(r):
        m = re.match(r"([A-Z]+)(\d+)", r)
        return (m.group(1), int(m.group(2)))

    rows = sorted(groups.items(), key=lambda kv: refkey(min((x.ref for x in kv[1]), key=refkey)))
    with open(path, "w", encoding="utf-8", newline="") as f:
        f.write("Qty,References,Value,Footprint,MPN,LCSC (fill in),Notes\n")
        for (value, fp, mpn), parts in rows:
            refs = " ".join(sorted((x.ref for x in parts), key=refkey))
            notes = "; ".join(sorted(set(x.note for x in parts if x.note and not x.ref.startswith("D"))))
            f.write('%d,"%s","%s","%s","%s",,"%s"\n' % (len(parts), refs, value, fp, mpn, notes))


def main():
    sch, nets, root = build()
    path = os.path.join(HERE, PROJECT + ".kicad_sch")
    with open(path, "w", encoding="utf-8", newline="\n") as f:
        f.write(dump(sch) + "\n")
    pro = os.path.join(HERE, PROJECT + ".kicad_pro")
    if not os.path.exists(pro):
        with open(pro, "w", encoding="utf-8", newline="\n") as f:
            f.write('{\n  "meta": {\n    "filename": "%s.kicad_pro",\n    "version": 3\n  }\n}\n' % PROJECT)
    write_bom(os.path.join(HERE, "BOM.csv"))
    single = sorted(n for n, m in nets.items() if len(m) < 2)
    print("wrote %s: %d parts, %d nets" % (path, len(design.PARTS), len(nets)))
    if single:
        print("WARNING single-pin nets:", single)


if __name__ == "__main__":
    main()

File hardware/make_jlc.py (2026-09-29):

"""Build JLCPCB order files from cable_tester.kicad_pcb into fab/:
  gerbers/ + cable_tester_gerbers.zip  (PCB order)
  BOM_JLC.csv, CPL_JLC.csv             (SMT assembly order, top side)

Run (board must be saved; can be open in KiCad):
  python make_jlc.py
"""
import csv
import os
import shutil
import subprocess
import zipfile

HERE = os.path.dirname(os.path.abspath(__file__))
CLI = os.environ.get("KICAD_CLI", r"C:\Program Files\KiCad\9.0\bin\kicad-cli.exe")
PCB = os.path.join(HERE, "cable_tester.kicad_pcb")
FAB = os.path.join(HERE, "fab")
GERB = os.path.join(FAB, "gerbers")

# Hand-soldered / not assembled by JLC: module, through-hole parts, optional header.
NOT_ASSEMBLED = ("A1", "J1", "J5", "SW1", "BZ1", "MH1", "MH2", "MH3", "MH4")

# (value, footprint name) -> (LCSC#, description). Verified on lcsc.com.
LCSC = {
    ("100n", "C_0603_1608Metric"): ("C14663", "100nF 50V X7R 0603 (Yageo CC0603KRX7R9BB104)"),
    ("10u", "C_0805_2012Metric"): ("C15850", "10uF 25V X5R 0805 (Samsung CL21A106KAYNNNE)"),
    ("330", "R_0603_1608Metric"): ("C23138", "330R 1% 0603 (0603WAF3300T5E)"),
    ("4k7", "R_0603_1608Metric"): ("C23162", "4.7k 1% 0603 (0603WAF4701T5E)"),
    ("1k", "R_0603_1608Metric"): ("C21190", "1k 1% 0603 (0603WAF1001T5E)"),
    ("10k", "R_0603_1608Metric"): ("C25804", "10k 1% 0603 (0603WAF1002T5E)"),
    ("4x220", "R_Array_Convex_4x0603"): ("C29719", "4x220R 0603x4 array (UniOhm 4D03WGJ0221T5E)"),
    ("MCP23017-E/SO", "SOIC-28W_7.5x17.9mm_P1.27mm"): ("C47023", "MCP23017-E/SO"),
    ("74AHCT1G125", "SOT-23-5"): ("C7484", "SN74AHCT1G125DBVR"),
    ("MMBT3904", "SOT-23"): ("C20526", "MMBT3904 (JSCJ)"),
    ("1N4148W", "D_SOD-123"): ("C81598", "1N4148W SOD-123"),
    ("WS2812B", "LED_WS2812B_PLCC4_5.0x5.0mm_P3.2mm"): ("C114586", "WS2812B-B/W (Worldsemi)"),
}
JST = ("C133065", "JST SM06B-GHS-TB(LF)(SN)")


def run(*args):
    subprocess.run([CLI, *args], check=True, stdout=subprocess.DEVNULL)


def gerbers():
    shutil.rmtree(GERB, ignore_errors=True)
    os.makedirs(GERB)
    run("pcb", "export", "gerbers", "--output", GERB + os.sep,
        "--layers", "F.Cu,B.Cu,F.Paste,F.Silkscreen,B.Silkscreen,F.Mask,B.Mask,Edge.Cuts",
        "--subtract-soldermask", "--no-x2", "--no-netlist", PCB)
    run("pcb", "export", "drill", "--output", GERB + os.sep, "--format", "excellon",
        "--drill-origin", "absolute", "--excellon-units", "mm", "--excellon-zeros-format", "decimal",
        "--excellon-oval-format", "alternate", "--excellon-separate-th", "--generate-map",
        "--map-format", "gerberx2", PCB)
    z = os.path.join(FAB, "cable_tester_gerbers.zip")
    with zipfile.ZipFile(z, "w", zipfile.ZIP_DEFLATED) as zf:
        for f in sorted(os.listdir(GERB)):
            zf.write(os.path.join(GERB, f), f)
    return z, sorted(os.listdir(GERB))


def assembly():
    pos = os.path.join(FAB, "_pos.csv")
    run("pcb", "export", "pos", "--output", pos, "--format", "csv", "--units", "mm",
        "--side", "front", PCB)
    rows = list(csv.DictReader(open(pos, encoding="utf-8")))
    os.remove(pos)
    groups, cpl, missing = {}, [], []
    for r in rows:
        ref = r["Ref"]
        if ref in NOT_ASSEMBLED:
            continue
        fp = r["Package"]
        if fp.startswith("JST_GH_SM06B"):
            lcsc = JST
            r["Val"] = "SM06B-GHS-TB"
        else:
            lcsc = LCSC.get((r["Val"], fp))
        if not lcsc:
            missing.append((ref, r["Val"], fp))
            continue
        groups.setdefault((r["Val"], fp, lcsc[0], lcsc[1]), []).append(ref)
        cpl.append([ref, "%.3fmm" % float(r["PosX"]), "%.3fmm" % float(r["PosY"]),
                    "Top", "%.1f" % (float(r["Rot"]) % 360)])
    with open(os.path.join(FAB, "BOM_JLC.csv"), "w", newline="", encoding="utf-8") as f:
        w = csv.writer(f)
        w.writerow(["Comment", "Designator", "Footprint", "LCSC Part #", "Description"])
        for (val, fp, lc, desc), refs in sorted(groups.items(), key=lambda kv: kv[1][0]):
            w.writerow([val, ",".join(refs), fp, lc, desc])
    with open(os.path.join(FAB, "CPL_JLC.csv"), "w", newline="", encoding="utf-8") as f:
        w = csv.writer(f)
        w.writerow(["Designator", "Mid X", "Mid Y", "Layer", "Rotation"])
        w.writerows(sorted(cpl))
    return groups, len(cpl), missing


if __name__ == "__main__":
    os.makedirs(FAB, exist_ok=True)
    z, files = gerbers()
    print("gerbers:", ", ".join(files))
    print("zip:", z)
    groups, n, missing = assembly()
    print("BOM lines: %d, placements: %d" % (len(groups), n))
    for m in missing:
        print("NO LCSC PART for", m)
